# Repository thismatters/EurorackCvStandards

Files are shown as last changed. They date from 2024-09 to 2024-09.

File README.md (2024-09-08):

# Control Voltage Standards

The Control Voltage Standards is a module for providing precise voltages. This module is enabled by a whole bunch of potentiometers.

The circuit here is based on the [CV Standards](https://yusynth.net/Modular/EN/STANDARDS/index.html) with minor tweaks to make it more Eurorack friendly. The changes I've made are thus:
* Selected resistors appropriate for +/-12V rails,
* Added polarity protection so that a backward power header doesn't fry anything (twin series schotty diodes: BAT54SL),
* Full surface mount design.

The Yusynth page is a treasure trove of information about this circuit that I am too amateur to claim as my own; please read that outstanding page before using this circuit. The page provides many details and other implementations of this circuit that you may find suitable.

The KiCAD project here uses the library/footprints [found in my companion repo](https://github.com/thismatters/EurorackKiCAD).

## Width

4hp on a standard 3U rack.

## Inputs

Twin 12 position switches which allow selection of `octave` and `semitone`. A jack allows input of control voltage to offset the selected tone.

## Outputs

Three buffered jacks output control voltage.

## Adjustment

Oh boy. TODO

## Vendors

There are part numbers in the [BOM](cv-standard.csv) for many of the parts (not for basic passives though) at the following vendors:

* [Mouser](https://www.mouser.com): Needs no introduction. Get your ICs from here (or [digikey](https://www.digikey.com)).
* [Tayda Electronics](https://www.taydaelectronics.com/): Good supplier for passive components; audio jacks, and potentiometers. Their audio jacks are slightly smaller than the thonkiconn from thonk.
* [Love My Switches](https://lovemyswitches.com/): Has [really good knobs](https://lovemyswitches.com/anodized-aluminum-knob-the-lo-fi-1-4-smooth-shaft-12-5mm-od/) to go on those potentiometers!
* [OSHPark](https://oshpark.com/): Fast and (relatively) cheap PCB manufacturer. I haven't done a prototype run yet... stay tuned.

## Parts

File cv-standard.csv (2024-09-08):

# | Reference | Qty | Value | Footprint | DNP | Vendor | PartNum
1 | C1, C2 | 2 | 22u 50V | Capacitor_THT:CP_Radial_D5.0mm_P2.50mm
2 | C3, C4 | 2 | 100n | Capacitor_SMD:C_0805_2012Metric
3 | C5, C6 | 2 | 100u 16V | Capacitor_THT:CP_Radial_D5.0mm_P2.50mm
4 | D1, D2 | 2 | BAT54S | Package_TO_SOT_SMD:SOT-23 |  | Mouser | 863-BAT54SLT1G
5 | D3 | 1 | 11V | Diode_SMD:D_MiniMELF
6 | D4, D5 | 2 | 3V | Diode_SMD:D_MiniMELF
7 | J1 | 1 | Conn_02x05_Odd_Even | Eurorack:PinHeader_2x05_P2.54mm_Vertical |  | Tayda | A-2939
8 | J2, J3, J4, J5 | 4 | AudioJack2_SwitchT | Eurorack:AudioJack2_Tayda_A-2566 |  | Tayda | A-2566
9 | J6, J9, J11, J13, J15, J17, J19, J21 | 8 | Conn_01x03_Pin | Connector_PinHeader_2.54mm:PinHeader_1x03_P2.54mm_Vertical
10 | J7, J8, J10, J12, J14, J16, J18, J20 | 8 | Conn_01x03_Socket | Connector_PinSocket_2.54mm:PinSocket_1x03_P2.54mm_Vertical
11 | R1, R2 | 2 | 10 | Resistor_SMD:R_0805_2012Metric
12 | R3 | 1 | 4.7K | Resistor_SMD:R_0805_2012Metric
13 | R4 | 1 | 18K | Resistor_SMD:R_0805_2012Metric
14 | R5, R6 | 2 | 470 | Resistor_SMD:R_0805_2012Metric
15 | R7, R8 | 2 | 110K | Resistor_SMD:R_0805_2012Metric
16 | R9 | 1 | 3.3M | Resistor_SMD:R_0805_2012Metric
17 | R10, R11, R12, R13 | 4 | 200K | Resistor_SMD:R_0805_2012Metric
18 | R14, R15 | 2 | 100K | Resistor_SMD:R_0805_2012Metric
19 | R16 | 1 | 1M | Resistor_SMD:R_0805_2012Metric
20 | R17, R18, R19 | 3 | 100 | Resistor_SMD:R_0805_2012Metric
21 | R20, R21 | 2 | 24K | Resistor_SMD:R_0805_2012Metric
22 | RV1, RV2, RV3, RV4, RV5, RV6, RV7, RV8, RV9, RV10 | 10 | 10K | Potentiometer_THT:Potentiometer_Bourns_3296W_Vertical
23 | RV11, RV12, RV13, RV14, RV15, RV16, RV17, RV18, RV19, RV20 | 10 | 1K | Potentiometer_THT:Potentiometer_Bourns_3296W_Vertical
24 | RV21, RV22 | 2 | 47K | Potentiometer_THT:Potentiometer_Bourns_3296W_Vertical
25 | SW1, SW2 | 2 | SW_Rotary12 | Eurorack:Switch_Rotary_NKK_MRK_112 |  | Mouser | 633-MRK112-BA
26 | U1, U2 | 2 | TL074 | Package_SO:SOIC-14_3.9x8.7mm_P1.27mm |  | Mouser | 595-TL074CDR

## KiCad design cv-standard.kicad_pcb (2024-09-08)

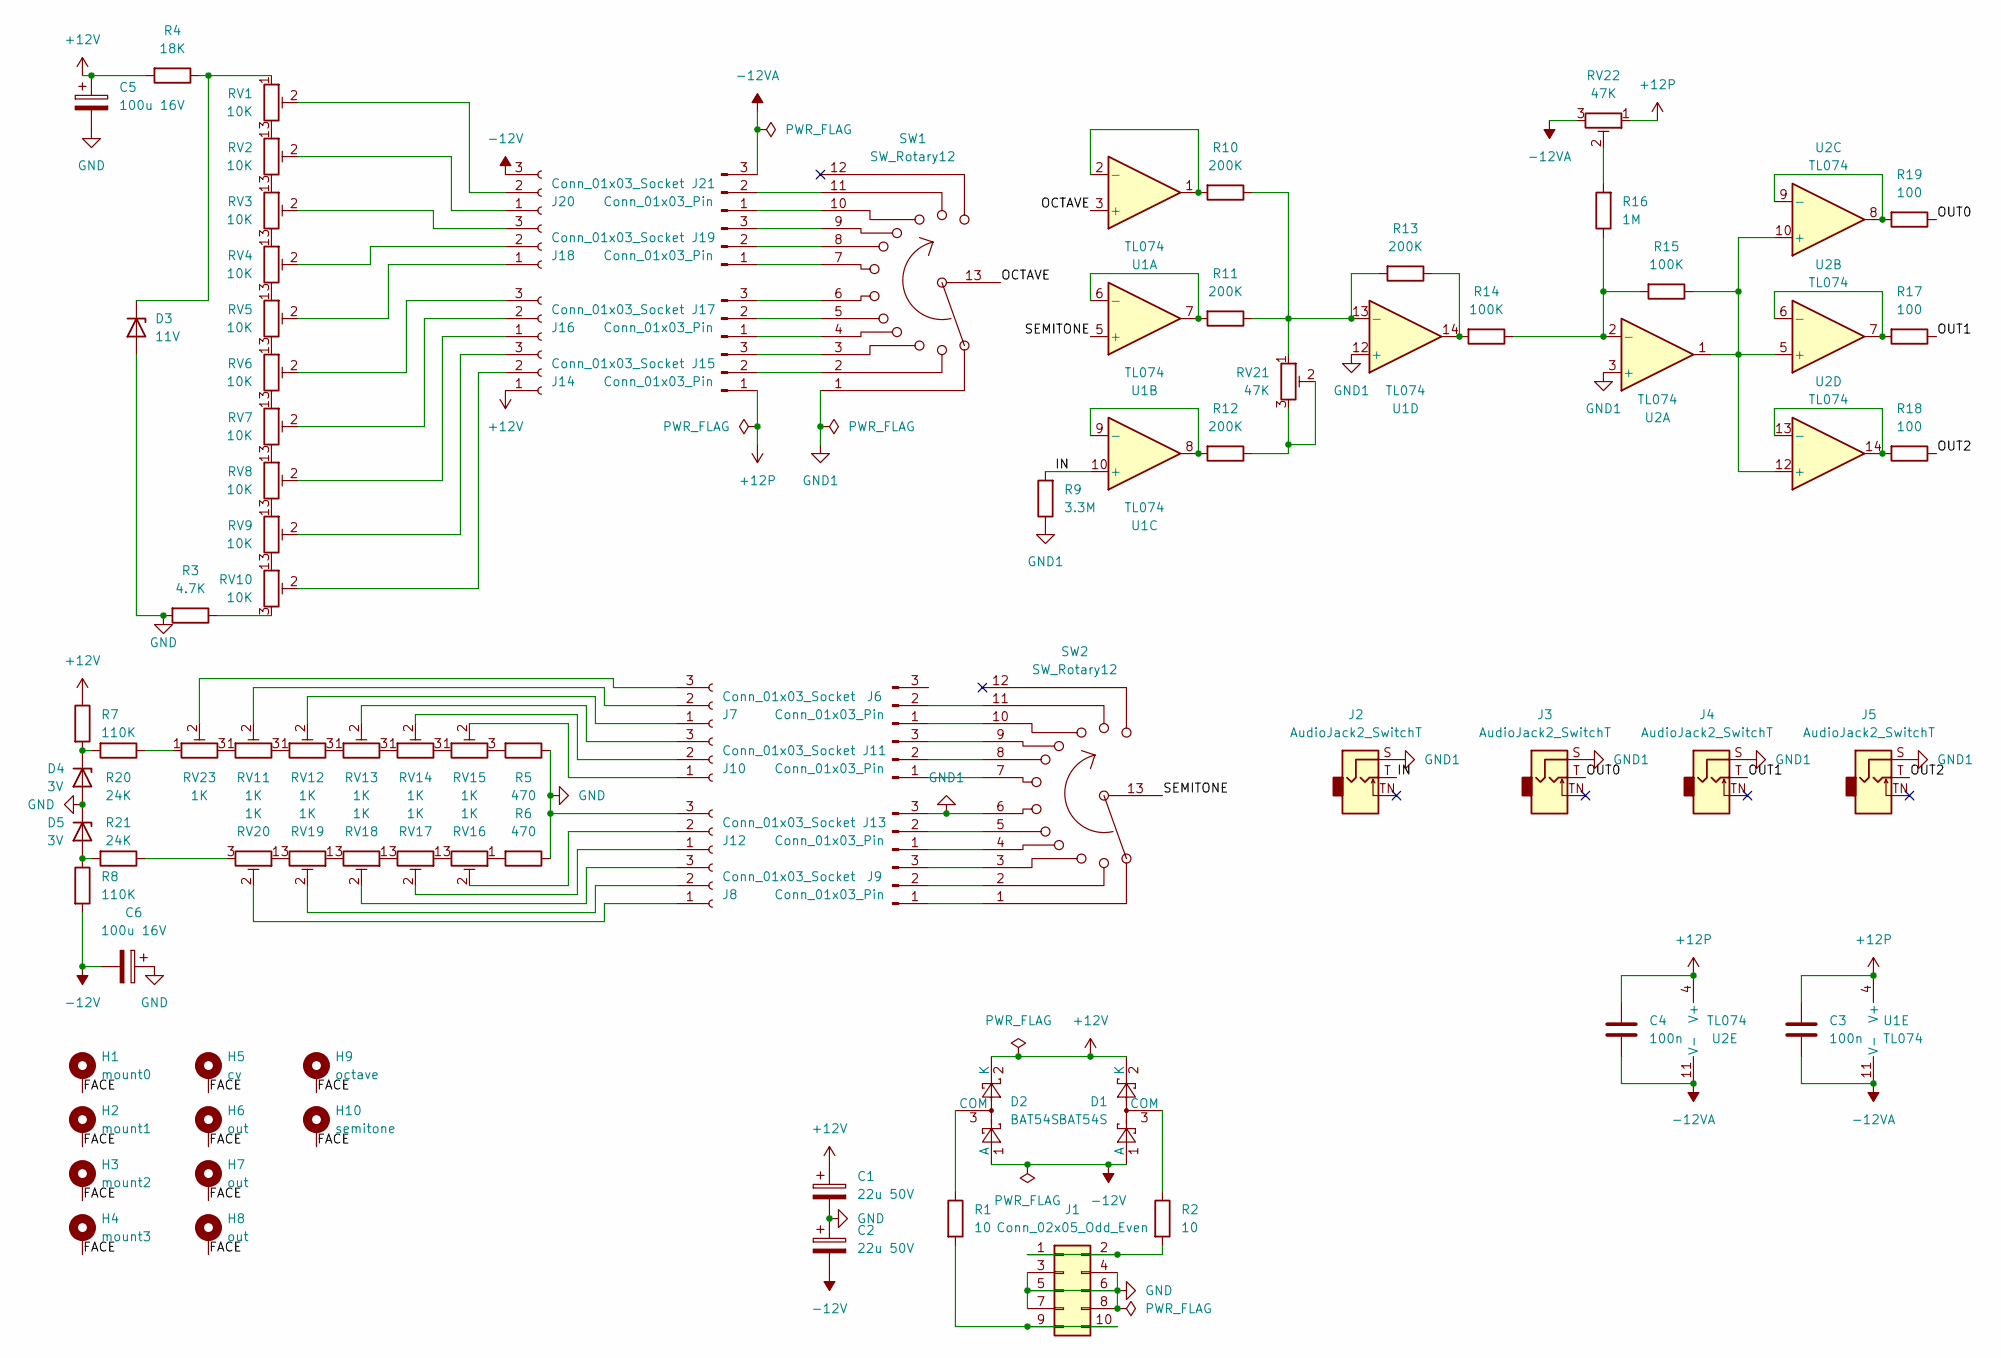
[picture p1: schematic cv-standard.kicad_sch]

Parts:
C1, C2: 22u 50V; CP_Radial_D5.0mm_P2.50mm
C3, C4: 100n; C_0805_2012Metric
C5, C6: 100u 16V; CP_Radial_D5.0mm_P2.50mm
D1, D2: BAT54S; SOT-23; PartNum 863-BAT54SLT1G
D3: 11V; D_MiniMELF
D4, D5: 3V; D_MiniMELF
H1: mount0; Mech-MountingHole
H2: mount1; Mech-MountingHole
H3: mount2; Mech-MountingHole
H4: mount3; Mech-MountingHole
H5: cv; Mech-AudioJack-Hole-Input-Voct
H6, H7, H8: out; Mech-AudioJack-Hole-Output-Voct
H9: octave; Mech-MRK-Hole
H10: semitone; Mech-MRK-Hole
J1: Conn_02x05_Odd_Even; PinHeader_2x05_P2.54mm_Vertical; PartNum A-2939
J2, J3, J4, J5: AudioJack2_SwitchT; AudioJack2_Tayda_A-2566; PartNum A-2566
J6, J9, J11, J13, J15, J17, J19, J21: Conn_01x03_Pin; PinHeader_1x03_P2.54mm_Vertical
J7, J8, J10, J12, J14, J16, J18, J20: Conn_01x03_Socket; PinSocket_1x03_P2.54mm_Vertical
R1, R2: 10; R_0805_2012Metric
R3: 4.7K; R_0805_2012Metric
R4: 18K; R_0805_2012Metric
R5, R6: 470; R_0805_2012Metric
R7, R8: 110K; R_0805_2012Metric
R9: 3.3M; R_0805_2012Metric
R10, R11, R12, R13: 200K; R_0805_2012Metric
R14, R15: 100K; R_0805_2012Metric
R16: 1M; R_0805_2012Metric
R17, R18, R19: 100; R_0805_2012Metric
R20, R21: 24K; R_0805_2012Metric
RV1, RV2, RV3, RV4, RV5, RV6, RV7, RV8, RV9, RV10: 10K; Potentiometer_Bourns_3296W_Vertical
RV11, RV12, RV13, RV14, RV15, RV16, RV17, RV18, RV19, RV20, RV23: 1K; Potentiometer_Bourns_3296W_Vertical
RV21, RV22: 47K; Potentiometer_Bourns_3296W_Vertical
SW1, SW2: SW_Rotary12; Switch_Rotary_NKK_MRK_112; PartNum 633-MRK112-BA
U1, U2: TL074; SOIC-14_3.9x8.7mm_P1.27mm; PartNum 595-TL074CDR

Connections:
+12P: C3.1, C4.1, J15.1, RV22.1, U1.4 (V+), U2.4 (V+)
+12V: C1.1, C5.1, D1.2 (K), D2.2 (K), J14.1, R4.2, R7.1
-12V: C2.2, C6.2, D1.1 (A), D2.1 (A), J20.3, R8.2
-12VA: C3.2, C4.2, J21.3, RV22.3, U1.11 (V-), U2.11 (V-)
/FACE: H1.1, H2.1, H3.1, H4.1, H5.1, H6.1, H7.1, H8.1, H9.1, H10.1
/IN: J2.T, R9.2, U1.10 (+)
/OCTAVE: SW1.13, U1.3 (+)
/OUT0: J3.T, R19.1
/OUT1: J4.T, R17.1
/OUT2: J5.T, R18.1
/SEMITONE: SW2.13, U1.5 (+)
GND: C1.2, C2.1, C5.2, C6.1, D3.2 (A), D4.2 (A), D5.1 (K), J1.3, J1.4, J1.5, J1.6, J1.7, J1.8, J12.3, R3.2, R5.1, R6.1
GND1: J2.S, J3.S, J4.S, J5.S, J13.3, R9.1, SW1.1, SW2.6, U1.12 (+), U2.3 (+)
unnamed: D1.3 (COM), R2.1
unnamed: D2.3 (COM), R1.1
unnamed: D3.1 (K), R4.1, RV1.1
unnamed: D4.1 (K), R7.2, R20.2
unnamed: D5.2 (A), R8.1, R21.2
unnamed: J1.1, J1.2, R2.2
unnamed: J1.9, J1.10, R1.2
unnamed: J6.1, SW2.10
unnamed: J6.2, SW2.11
unnamed: J7.1, RV12.2
unnamed: J7.2, RV11.2
unnamed: J7.3, RV23.2
unnamed: J8.1, RV20.2
unnamed: J8.2, RV19.2
unnamed: J8.3, RV18.2
unnamed: J9.1, SW2.1
unnamed: J9.2, SW2.2
unnamed: J9.3, SW2.3
unnamed: J10.1, RV15.2
unnamed: J10.2, RV14.2
unnamed: J10.3, RV13.2
unnamed: J11.1, SW2.7
unnamed: J11.2, SW2.8
unnamed: J11.3, SW2.9
unnamed: J12.1, RV17.2
unnamed: J12.2, RV16.2
unnamed: J13.1, SW2.4
unnamed: J13.2, SW2.5
unnamed: J14.2, RV10.2
unnamed: J14.3, RV9.2
unnamed: J15.2, SW1.2
unnamed: J15.3, SW1.3
unnamed: J16.1, RV8.2
unnamed: J16.2, RV7.2
unnamed: J16.3, RV6.2
unnamed: J17.1, SW1.4
unnamed: J17.2, SW1.5
unnamed: J17.3, SW1.6
unnamed: J18.1, RV5.2
unnamed: J18.2, RV4.2
unnamed: J18.3, RV3.2
unnamed: J19.1, SW1.7
unnamed: J19.2, SW1.8
unnamed: J19.3, SW1.9
unnamed: J20.1, RV2.2
unnamed: J20.2, RV1.2
unnamed: J21.1, SW1.10
unnamed: J21.2, SW1.11
unnamed: R3.1, RV10.3
unnamed: R5.2, RV15.3
unnamed: R6.2, RV16.1
unnamed: R12.1, RV21.2, RV21.3
unnamed: R13.1, R14.2, U1.14
unnamed: R16.2, RV22.2
unnamed: R20.1, RV23.1
unnamed: R21.1, RV20.3
unnamed: RV1.3, RV2.1
unnamed: RV2.3, RV3.1
unnamed: RV3.3, RV4.1
unnamed: RV4.3, RV5.1
unnamed: RV5.3, RV6.1
unnamed: RV6.3, RV7.1
unnamed: RV7.3, RV8.1
unnamed: RV8.3, RV9.1
unnamed: RV9.3, RV10.1
unnamed: RV11.1, RV23.3
unnamed: RV11.3, RV12.1
unnamed: RV12.3, RV13.1
unnamed: RV13.3, RV14.1
unnamed: RV14.3, RV15.1
unnamed: RV16.3, RV17.1
unnamed: RV17.3, RV18.1
unnamed: RV18.3, RV19.1
unnamed: RV19.3, RV20.1
unnamed: R10.2, U1.1, U1.2 (-)
unnamed: R11.2, U1.6 (-), U1.7
unnamed: R12.2, U1.8, U1.9 (-)
unnamed: R10.1, R11.1, R13.2, RV21.1, U1.13 (-)
unnamed: R14.1, R15.2, R16.1, U2.2 (-)
unnamed: R15.1, U2.1, U2.5 (+), U2.10 (+), U2.12 (+)
unnamed: R17.2, U2.6 (-), U2.7
unnamed: R19.2, U2.8, U2.9 (-)
unnamed: R18.2, U2.13 (-), U2.14

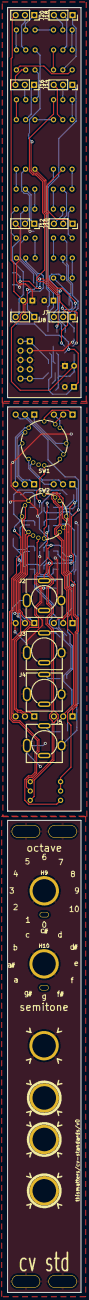
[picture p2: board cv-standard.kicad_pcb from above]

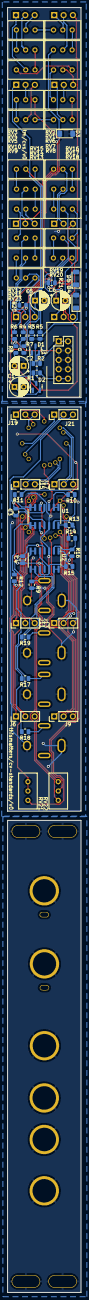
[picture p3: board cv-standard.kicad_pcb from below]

Board: 2 copper layers, 20.0 x 349.8 mm, 90 parts (66 on the bottom side), 96 nets.
